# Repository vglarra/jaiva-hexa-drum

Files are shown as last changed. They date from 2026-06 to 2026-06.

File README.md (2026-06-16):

# Jaiva Hexa Drum

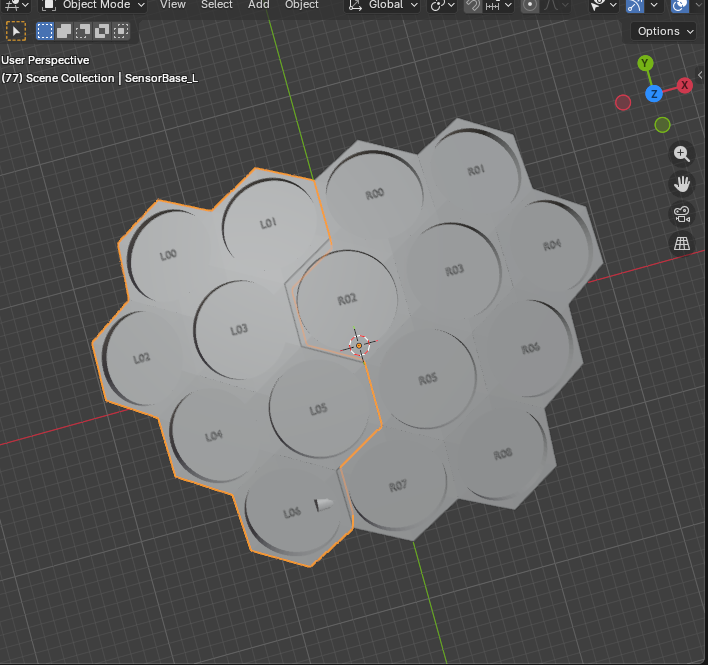
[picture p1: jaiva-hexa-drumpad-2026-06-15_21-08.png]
Jaiva Hexa Drum pad render


A parametric hexagonal drum pad designed in Blender, intended for physical fabrication (3D printing). The pad consists of a dome-shaped array of hexagonal tiles, each with a recessed cup to hold a circular sensor (e.g. piezo disc), and alignment pin holes at the tile boundaries for assembly.

## Overview

The pad is split into two halves — **Left** and **Right** — that join along a vertical center line. This makes it printable on standard-sized 3D printers. Alignment dowel pins lock the halves together at four pair points.

The tile surface follows a cosine dome profile, so the playing surface is gently curved rather than flat.

## Files

| File | Description |
|---|---|
| `jaiva-hexa-drum-script.py` | Blender Python script that generates the full geometry |
| `jaiva-drum-hexa-cut-e-dowels.blend` | Blender project file |

## How It Works

The script (`jaiva-hexa-drum-script.py`) is run inside Blender's scripting workspace. It:

1. Lays out a 16-tile hexagonal grid (4 rows, flat-top orientation)
2. Finds the best vertical split to divide the grid into Left (L) and Right (R) halves
3. For each tile:
   - Builds a hexagonal prism
   - Displaces the top vertices along a cosine dome surface
   - Cuts a cylindrical cup recess for the sensor
   - Cuts a pin hole through the appropriate side face (for assigned tiles)
4. Joins each half into a single mesh (`SensorBase_L`, `SensorBase_R`)
5. Exports both halves as `.stl` and `.obj` files alongside the `.blend` file

## Key Parameters

| Parameter | Value | Description |
|---|---|---|
| `SENSOR_DIA` | 69 mm | Diameter of the sensor cup recess |
| `PLATE_H` | 6 mm | Thickness of each hex tile |
| `HEX_FLAT_WIDTH` | 77 mm | Flat-to-flat width of each hexagon |
| `DOME_HEIGHT` | 40 mm | Maximum height of the dome at center |
| `DOME_RADIUS` | 210 mm | Radius of the dome profile |
| `PIN_DIAMETER` | 15 mm | Dowel pin diameter |
| `PIN_DEPTH` | 20 mm | Depth of pin holes |
| `PIN_Z` | 20 mm | Vertical position of pin hole centers |

## Tile Grid Layout

The grid contains 16 hexagonal tiles arranged in 4 rows:

```
Row 3 (top):    L L L L         (4 tiles)
Row 2:        L L L R R R R R   (tiles span split)
Row 1:          L L R R R R     (tiles span split)
Row 0 (bot):      L L R R R     (tiles span split)
```

The exact split is computed automatically to find the largest gap between tile columns.

## Pin Hole Pairs

Four pairs of alignment pin holes are drilled across the split seam:

| Pair | Left tile | Right tile |
|---|---|---|
| Pair 1 | L01 (right face) | R00 (left face) |
| Pair 2 | L03 (right face) | R02 (left face) |
| Pair 3 | L05 (right face) | R05 (left face) |
| Pair 4 | L06 (right face) | R07 (left face) |

Holes are cut **per-tile before joining** to guarantee the boolean cutter always intersects solid material.

## Running the Script

1. Open `jaiva-drum-hexa-cut-e-dowels.blend` in Blender (3.x or later recommended)
2. Go to the **Scripting** workspace
3. Open `jaiva-hexa-drum-script.py`
4. Click **Run Script**

The script clears any previous geometry, rebuilds all tiles, joins each half, and exports the STL/OBJ files to the same directory as the `.blend` file.

## Output

- `hex_dome_v52_L.stl` — left half, ready to print
- `hex_dome_v52_R.stl` — right half, ready to print
- (`.obj` fallback if STL export is unavailable in the Blender version)

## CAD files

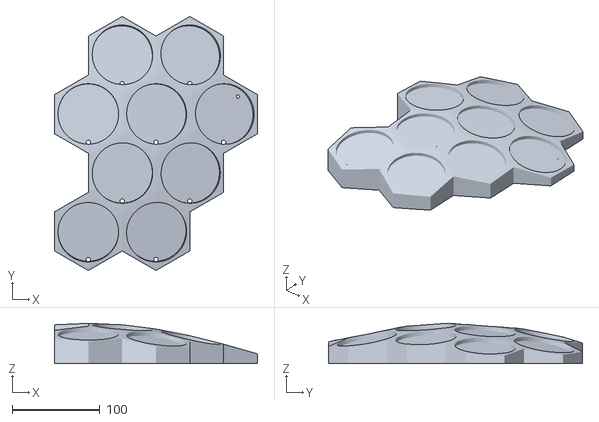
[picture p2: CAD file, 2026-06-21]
hex_dome_v1_R.stl
231.0 x 289.0 x 45.9

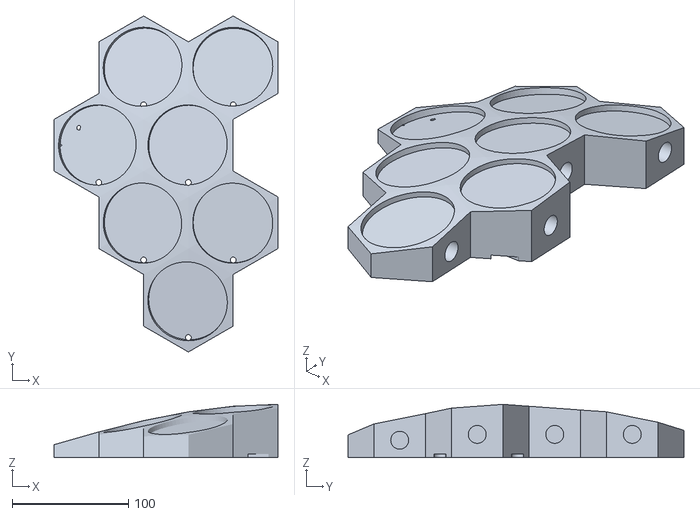
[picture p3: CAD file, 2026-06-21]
hex_dome_v1_L.stl
192.5 x 289.0 x 45.9

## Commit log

2026-06-16 Initial commit: Blender hex dome drum pad script, model, render, and README
    [jaiva-drum-hexa-cut-e-dowels.blend]
2026-06-16 Add 5mm wire hole per tile (V53): tangent to cup inner wall, vertical through back face
    Each of the 16 tiles now has a 5mm-diameter vertical hole drilled at
    CUP_R - WIRE_HOLE_RADIUS (32mm) from the cup center in the -Y direction,
    so the hole edge is tangent to the cup inner wall. The cutter passes fully
    from z=0 (back face) through the top of the dome tile, providing a wiring
    passage for each sensor.
2026-06-16 Add .gitignore: exclude generated STL/OBJ and binary .blend files
    Script is the source of truth; binary files add history weight with no diffable value.
    [jaiva-drum-hexa-cut-e-dowels.blend]
2026-06-16 Shift Teensy cavity 6mm from seam to leave solid left wall (V54)
    Added CAVITY_X_OFFSET=6mm so the cavity starts at x=6 instead of x=0,
    giving a 6mm wall between the split seam and the cavity left face.
2026-06-16 Move Teensy cavity 3mm further from seam (CAVITY_X_OFFSET 6→9mm)
2026-06-16 Move Teensy cavity to per-tile boolean before join (V54 fix)
    The post-join boolean on a non-watertight mesh caused the slicer to see
    open/missing faces. Cutting per-tile (same as pin holes and wire holes)
    guarantees the cutter always hits solid material. overlaps_cavity() uses
    a bounding-box check to identify which right-half tiles need the cut
    (R02, R03, R05 for the current 9x50x90mm cavity footprint).
2026-06-16 Add wiring canals routing all 16 sensor holes to Teensy cavity (V54)
    12-segment canal network (10mm wide, 5mm deep) cut per-tile before join.
    R07 rises straight at x=0 to avoid L-shape; R08 rises at x=77. Left half
    routes via middle trunk. Canal at bottom row stays within tile bodies.
2026-06-17 Move left-half trunk-to-trunk vertical canals from x=-0.5H to x=-H (V55)
    Removes the two vertical canal segments near the seam on the left half
    (at x=-0.5H) and replaces them at x=-H, away from the left/right split.
    Routing connectivity preserved: new verticals meet the existing middle
    trunk (segment [0]) which runs to the cavity left edge at x=9mm.
2026-06-18 Add wiring canal routing with correct depth (V65)
    - CANAL_DEPTH 5→3mm: groove no longer cuts through full 6mm plate
    - Canal cutter z: -1→6mm changed to -0.1→3mm, leaving 3mm solid roof
    - Export filename fixed to hex_dome_v1_*.stl (overwrites each run)
    - Canal segments from V56 preserved (12 segments, all tiles, FLOAT solver)
2026-06-18 Add V65 exported STL files
    hex_dome_v1_L.stl and hex_dome_v1_R.stl — left and right halves
    ready for slicing.
    [hex_dome_v1_L.stl, hex_dome_v1_R.stl]
2026-06-19 Flat-first solid with normal-based dome and FLOAT cavity (V79)
    Build order:
    1. Flat hex plate (solid-first, no interior walls)
    2. Canal cuts on flat geometry with EXACT (clean axis-aligned intersections)
    3. Dome displacement via face normals (robust vs EXACT z-drift that broke R07)
    4. Cup / wire / pin holes with EXACT post-dome
    5. Teensy cavity (FLOAT) applied last — avoids 2-shell enclosed-void
    Key improvements over V65:
    - No per-tile join → no paired interior walls → slicer correctly resolves topology
    - Normal-based dome displacement catches all top-face vertices regardless of
    floating-point drift from EXACT boolean
    - Cavity uses FLOAT to keep pocket open at z=0 face (no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
    [hex_dome_v1_L.stl, hex_dome_v1_R.stl]
2026-06-19 Honest failure reporting + R07 seam fix + FLOAT cavity (V82)
    - Track all boolean failures in FAILURES list, report at end instead of
    printing "✓" on silent failures — was masking why canals disappeared
    - R07 post-dome canal cutter biased fully into right half so it no longer
    sits coplanar with the seam face (degenerate sliver was causing the cut
    to silently fail or produce corrupt geometry)
    - Cavity back to FLOAT (EXACT was sealing the bottom face → 0 shell)
    - Cup / wire hole: FLOAT (curved dome surface, more robust)
    - Canals / pins: EXACT (flat geometry, clean)
    [hex_dome_v1_L.stl, hex_dome_v1_R.stl]
2026-06-19 Try-before-commit boolean strategy, pinpoint non-manifold pins (V85)
    V83: stronger end-of-build cleanup pass
    V84: per-cut manifold tracking pinpointed L01 Pair1 and L06 Pair4 pins
    as the exact source of all 132 non-manifold edges (+66 each);
    L03/L05 pins and all cups/wires/canals were clean
    V85: "try before you commit" — each boolean is first attempted on a
    disposable copy; if it leaves non-manifold/degenerate geometry the
    other solver is tried on a fresh copy; only the clean result is
    kept. More robust than pre-selecting EXACT vs FLOAT per feature
    type, because solver failures are geometry-specific and not
    predictable from tile position alone.
    Co-Author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
    [hex_dome_v1_L.stl, hex_dome_v1_R.stl]
2026-06-19 Bottom-face label offsets refined, font +10% (V86-V89)
    V86: per-pair PIN_Z override — Pair4 (L06/R07) lowered 5mm for dome clearance
    V87: real bottom-face tile engraving (had Z-position bug)
    V88: fixed Z-position; L03/L06/R07/R08 at -10mm, R05 at +25mm
    V89: further offset refinement after visual confirmation — L03/L06/R07/R08
    at -20mm, R05 at +40mm; font size 8.0→8.8mm (+10%)
    [hex_dome_v1_L.stl, hex_dome_v1_R.stl]
2026-06-19 Add R00 dedicated cable port + bump to V90
    10mm bore along Y through R00's exterior wall, routed straight to the
    Teensy cavity as an independent path from the sensor wire-hole shaft.
    Z is sampled across the full path length to guarantee the bore stays
    inside material even where the dome is thinnest.
    [hex_dome_v1_L.stl, hex_dome_v1_R.stl]
2026-06-20 R07 canal reordered before wire holes + canal fillets/caps (V91-V95)
    V95 root-cause fix: R07's canal was being cut in Step 4b, after all
    tile wire holes existed, causing 11 persistent non-manifold edges.
    Moved to Step 3b (post-dome, pre-tile-cuts) to match every other
    canal's clean-material condition.
    Also adds: rounded inside corners at canal junctions (V91), rounded
    dead-end caps (V92), R07 canal depth/centering fix (V93/V94), and
    safe_cut negative-score bug fix (V94).
    [hex_dome_v1_L.stl, hex_dome_v1_R.stl]
2026-06-20 Add mounting holes on left tiles, bump to V103
    V101-V102: 4 mounting holes (L00/L02 8mm, L04/L06 17mm, 30mm deep)
    bored through each tile's natural exterior wall at a per-tile angle.
    L06 switched from SW to west wall after margin check found SW 0.3mm
    too thin.
    V103: adds a 5th hole on L01 (16mm dia, 30mm deep, NW wall — same
    direction as L00, confirmed open-air wall with 4.3mm margin).
    [hex_dome_v1_L.stl, hex_dome_v1_R.stl]
2026-06-21 Add 30 rear-face cover attachment holes, bump to V106
    REAR_HOLE_DIA=13mm, REAR_HOLE_DEPTH=4mm. Holes placed algorithmically
    across all tiles except R05 (no viable spot due to canal/pin/cavity
    constraints). Hole positions manually tuned by user.
    [hex_dome_v1_L.stl, hex_dome_v1_R.stl]
2026-06-21 Add bronze insert pilot holes concentric with rear mount holes, bump to V108
    INSERT_HOLE_DIA=4mm, INSERT_HOLE_DEPTH=10mm, drilled concentrically into
    every REAR_MOUNT_HOLES entry so moving a rear hole automatically moves its
    insert pilot. Also synced REAR_HOLE_DIA comment (was 10.0 → 13.0) and
    aligned REAR_MOUNT_HOLES coordinate formatting.
    [hex_dome_v1_L.stl, hex_dome_v1_R.stl]
